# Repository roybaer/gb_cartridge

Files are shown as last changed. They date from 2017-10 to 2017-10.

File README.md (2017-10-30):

# GB Cartridge

This repository contains various PCB designs for Game Boy cartridges.

## Board characteristics

The individual designs have the following characteristics:

Board marking     | ROM    | RAM     | RAM backup                 | Technology | Memory Bank Controller
------------------|--------|---------|----------------------------|------------|--------------------------------
ROM+RAM(+BATT)    | 32 KiB | 8 KiB   | external battery/capacitor | SMD        | none
ROM+RAM+BATT      | 32 KiB | 8 KiB   | coin cell battery holder   | SMD        | none
ROM+RAM+BATT EVAL | 32 KiB | 8 KiB   | external battery           | THT        | none
ROM+MBC+RAM+BATT  | 1 MiB  | 128 KiB | coin cell battery holder   | SMD        | 74xx ICs loosely imitating MBC5

So far, only __ROM+RAM+BATT__ and __ROM+RAM+BATT EVAL__ have been manufactured and only the ROM related functionality has been tested.

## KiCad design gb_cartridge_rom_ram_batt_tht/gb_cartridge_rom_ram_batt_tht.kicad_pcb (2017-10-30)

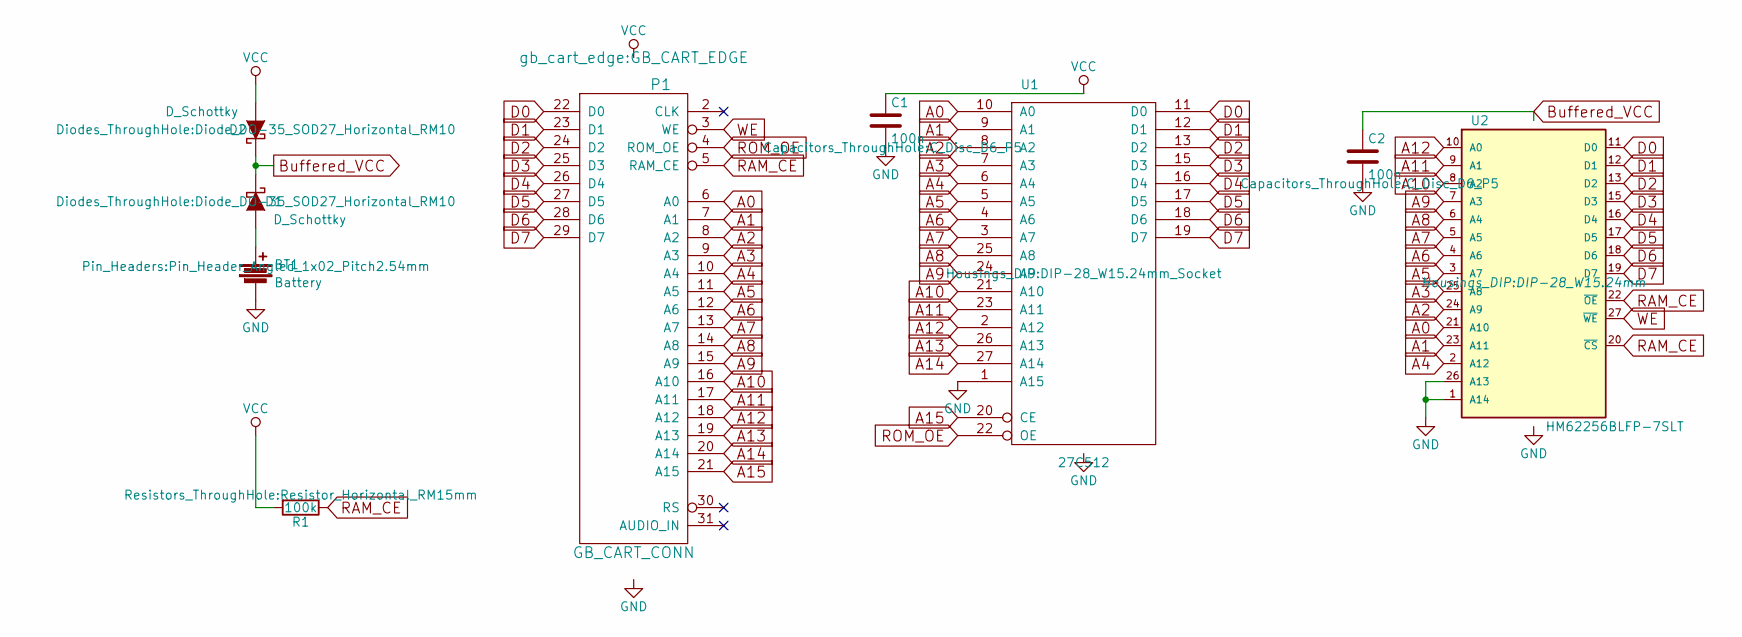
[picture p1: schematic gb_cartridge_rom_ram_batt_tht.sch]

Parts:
BT1: Battery; Pin_Header_Angled_1x02_Pitch2.54mm
C1, C2: 100n; C_Disc_D6_P5
D1, D2: D_Schottky; Diode_DO-35_SOD27_Horizontal_RM10
P1: GB_CART_CONN; GB_CART_EDGE
R1: 100k; Resistor_Horizontal_RM15mm
U1: 27C512; DIP-28_W15.24mm_Socket
U2: HM62256BLFP-7SLT; DIP-28_W15.24mm

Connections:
A0: P1.6 (A0), U1.10 (A0), U2.21 (A10)
A1: P1.7 (A1), U1.9 (A1), U2.23 (A11)
A2: P1.8 (A2), U1.8 (A2), U2.24 (A9)
A3: P1.9 (A3), U1.7 (A3), U2.25 (A8)
A4: P1.10 (A4), U1.6 (A4), U2.2 (A12)
A5: P1.11 (A5), U1.5 (A5), U2.3 (A7)
A6: P1.12 (A6), U1.4 (A6), U2.4 (A6)
A7: P1.13 (A7), U1.3 (A7), U2.5 (A5)
A8: P1.14 (A8), U1.25 (A8), U2.6 (A4)
A9: P1.15 (A9), U1.24 (A9), U2.7 (A3)
A10: P1.16 (A10), U1.21 (A10), U2.8 (A2)
A11: P1.17 (A11), U1.23 (A11), U2.9 (A1)
A12: P1.18 (A12), U1.2 (A12), U2.10 (A0)
A13: P1.19 (A13), U1.26 (A13)
A14: P1.20 (A14), U1.27 (A14)
A15: P1.21 (A15), U1.20 (CE)
D0: P1.22 (D0), U1.11 (D0), U2.11 (D0)
D1: P1.23 (D1), U1.12 (D1), U2.12 (D1)
D2: P1.24 (D2), U1.13 (D2), U2.13 (D2)
D3: P1.25 (D3), U1.15 (D3), U2.15 (D3)
D4: P1.26 (D4), U1.16 (D4), U2.16 (D4)
D5: P1.27 (D5), U1.17 (D5), U2.17 (D5)
D6: P1.28 (D6), U1.18 (D6), U2.18 (D6)
D7: P1.29 (D7), U1.19 (D7), U2.19 (D7)
GND: BT1.2, C1.2, C2.2, P1.32 (GND), U1.1 (A15), U1.14 (GND), U2.1 (A14), U2.14 (GND), U2.26 (A13)
unnamed: BT1.1, D1.2 (A)
RAM_CE: P1.5 (RAM_CE), R1.1, U2.20 (~CS), U2.22 (~OE)
ROM_OE: P1.4 (ROM_OE), U1.22 (OE)
WE: P1.3 (WE), U2.27 (~WE)

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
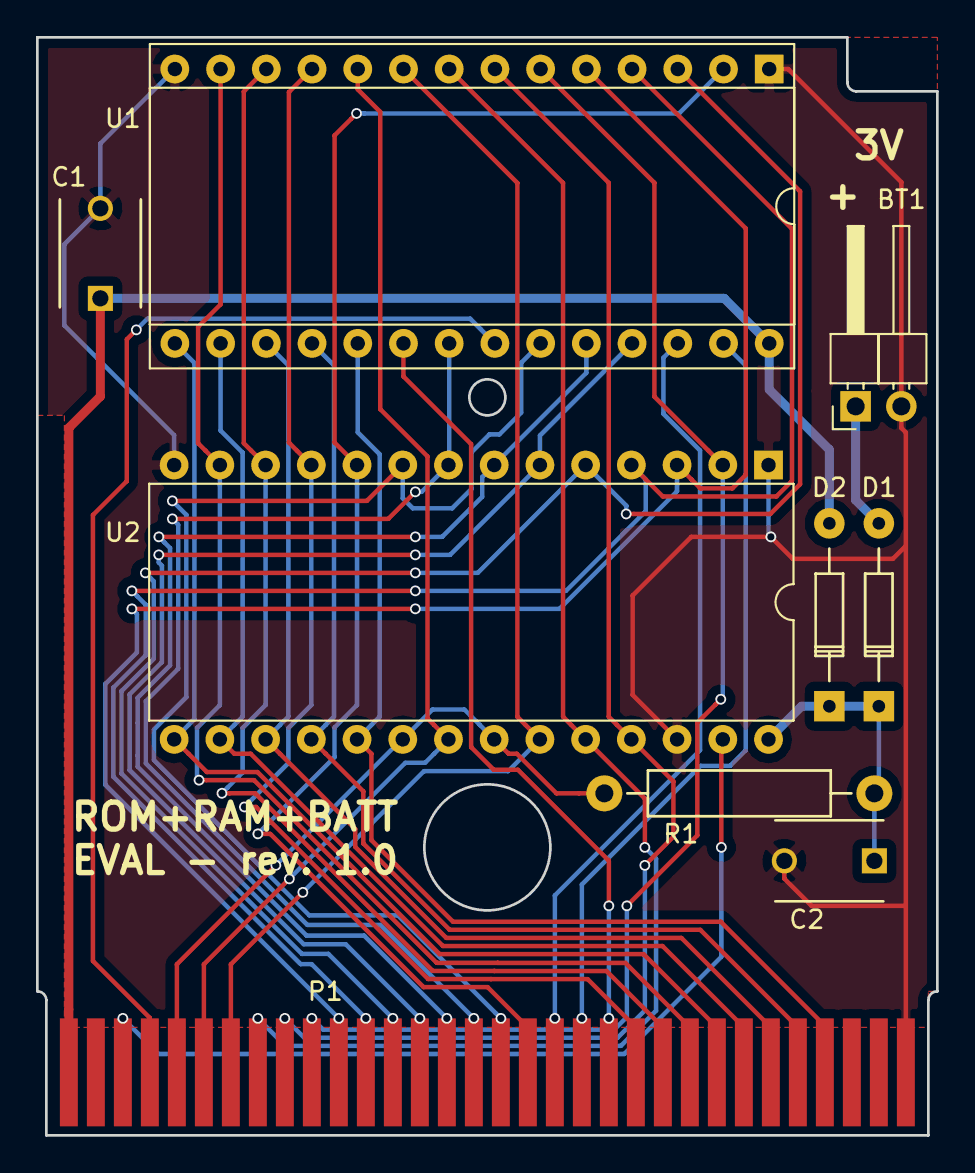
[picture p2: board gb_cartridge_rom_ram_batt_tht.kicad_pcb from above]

Board: 2 copper layers, 50.0 x 61.0 mm, 9 parts (0 on the bottom side), 30 nets.

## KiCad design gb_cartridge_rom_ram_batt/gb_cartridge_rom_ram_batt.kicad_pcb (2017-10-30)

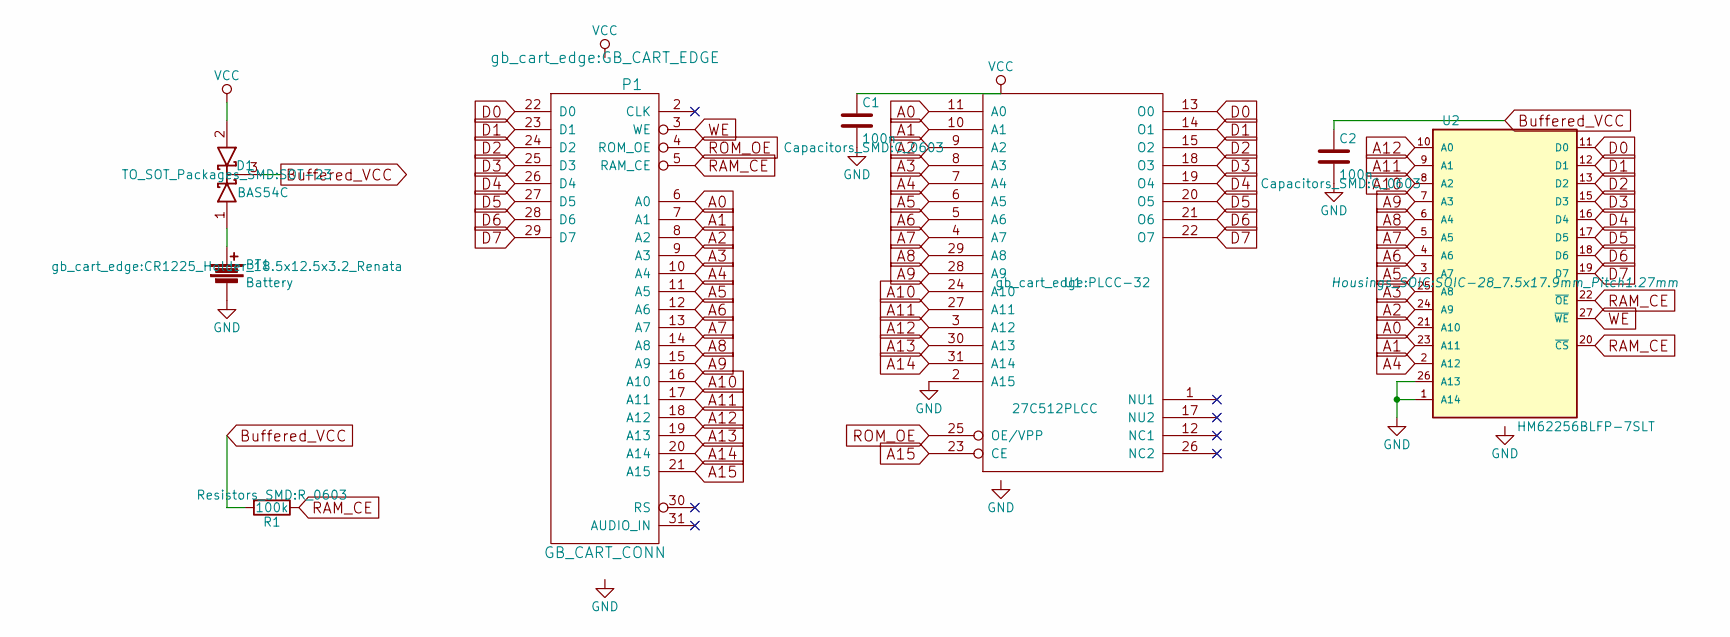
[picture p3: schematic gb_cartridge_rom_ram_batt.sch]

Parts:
BT1: Battery; CR1225_Holder_18.5x12.5x3.2_Renata
C1, C2: 100n; C_0603
D1: BAS54C; SOT-23
P1: GB_CART_CONN; GB_CART_EDGE
R1: 100k; R_0603
U1: 27C512PLCC; PLCC-32
U2: HM62256BLFP-7SLT; SOIC-28_7.5x17.9mm_Pitch1.27mm

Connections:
A0: P1.6 (A0), U1.11 (A0), U2.21 (A10)
A1: P1.7 (A1), U1.10 (A1), U2.23 (A11)
A2: P1.8 (A2), U1.9 (A2), U2.24 (A9)
A3: P1.9 (A3), U1.8 (A3), U2.25 (A8)
A4: P1.10 (A4), U1.7 (A4), U2.2 (A12)
A5: P1.11 (A5), U1.6 (A5), U2.3 (A7)
A6: P1.12 (A6), U1.5 (A6), U2.4 (A6)
A7: P1.13 (A7), U1.4 (A7), U2.5 (A5)
A8: P1.14 (A8), U1.29 (A8), U2.6 (A4)
A9: P1.15 (A9), U1.28 (A9), U2.7 (A3)
A10: P1.16 (A10), U1.24 (A10), U2.8 (A2)
A11: P1.17 (A11), U1.27 (A11), U2.9 (A1)
A12: P1.18 (A12), U1.3 (A12), U2.10 (A0)
A13: P1.19 (A13), U1.30 (A13)
A14: P1.20 (A14), U1.31 (A14)
A15: P1.21 (A15), U1.23 (CE)
D0: P1.22 (D0), U1.13 (O0), U2.11 (D0)
D1: P1.23 (D1), U1.14 (O1), U2.12 (D1)
D2: P1.24 (D2), U1.15 (O2), U2.13 (D2)
D3: P1.25 (D3), U1.18 (O3), U2.15 (D3)
D4: P1.26 (D4), U1.19 (O4), U2.16 (D4)
D5: P1.27 (D5), U1.20 (O5), U2.17 (D5)
D6: P1.28 (D6), U1.21 (O6), U2.18 (D6)
D7: P1.29 (D7), U1.22 (O7), U2.19 (D7)
GND: BT1.2, C1.2, C2.2, P1.32 (GND), U1.2 (A15), U1.16 (GND), U2.1 (A14), U2.14 (GND), U2.26 (A13)
unnamed: BT1.1, D1.1 (A)
RAM_CE: P1.5 (RAM_CE), R1.1, U2.20 (~CS), U2.22 (~OE)
ROM_OE: P1.4 (ROM_OE), U1.25 (OE/VPP)
WE: P1.3 (WE), U2.27 (~WE)

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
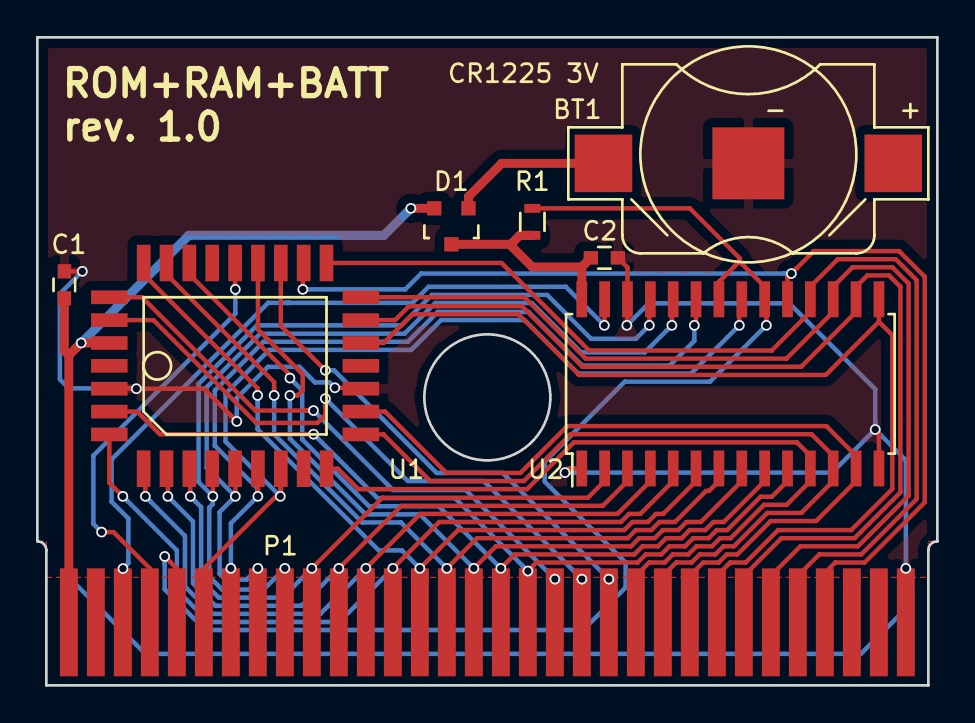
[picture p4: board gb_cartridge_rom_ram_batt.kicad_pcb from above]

Board: 2 copper layers, 50.0 x 36.0 mm, 8 parts (0 on the bottom side), 30 nets.

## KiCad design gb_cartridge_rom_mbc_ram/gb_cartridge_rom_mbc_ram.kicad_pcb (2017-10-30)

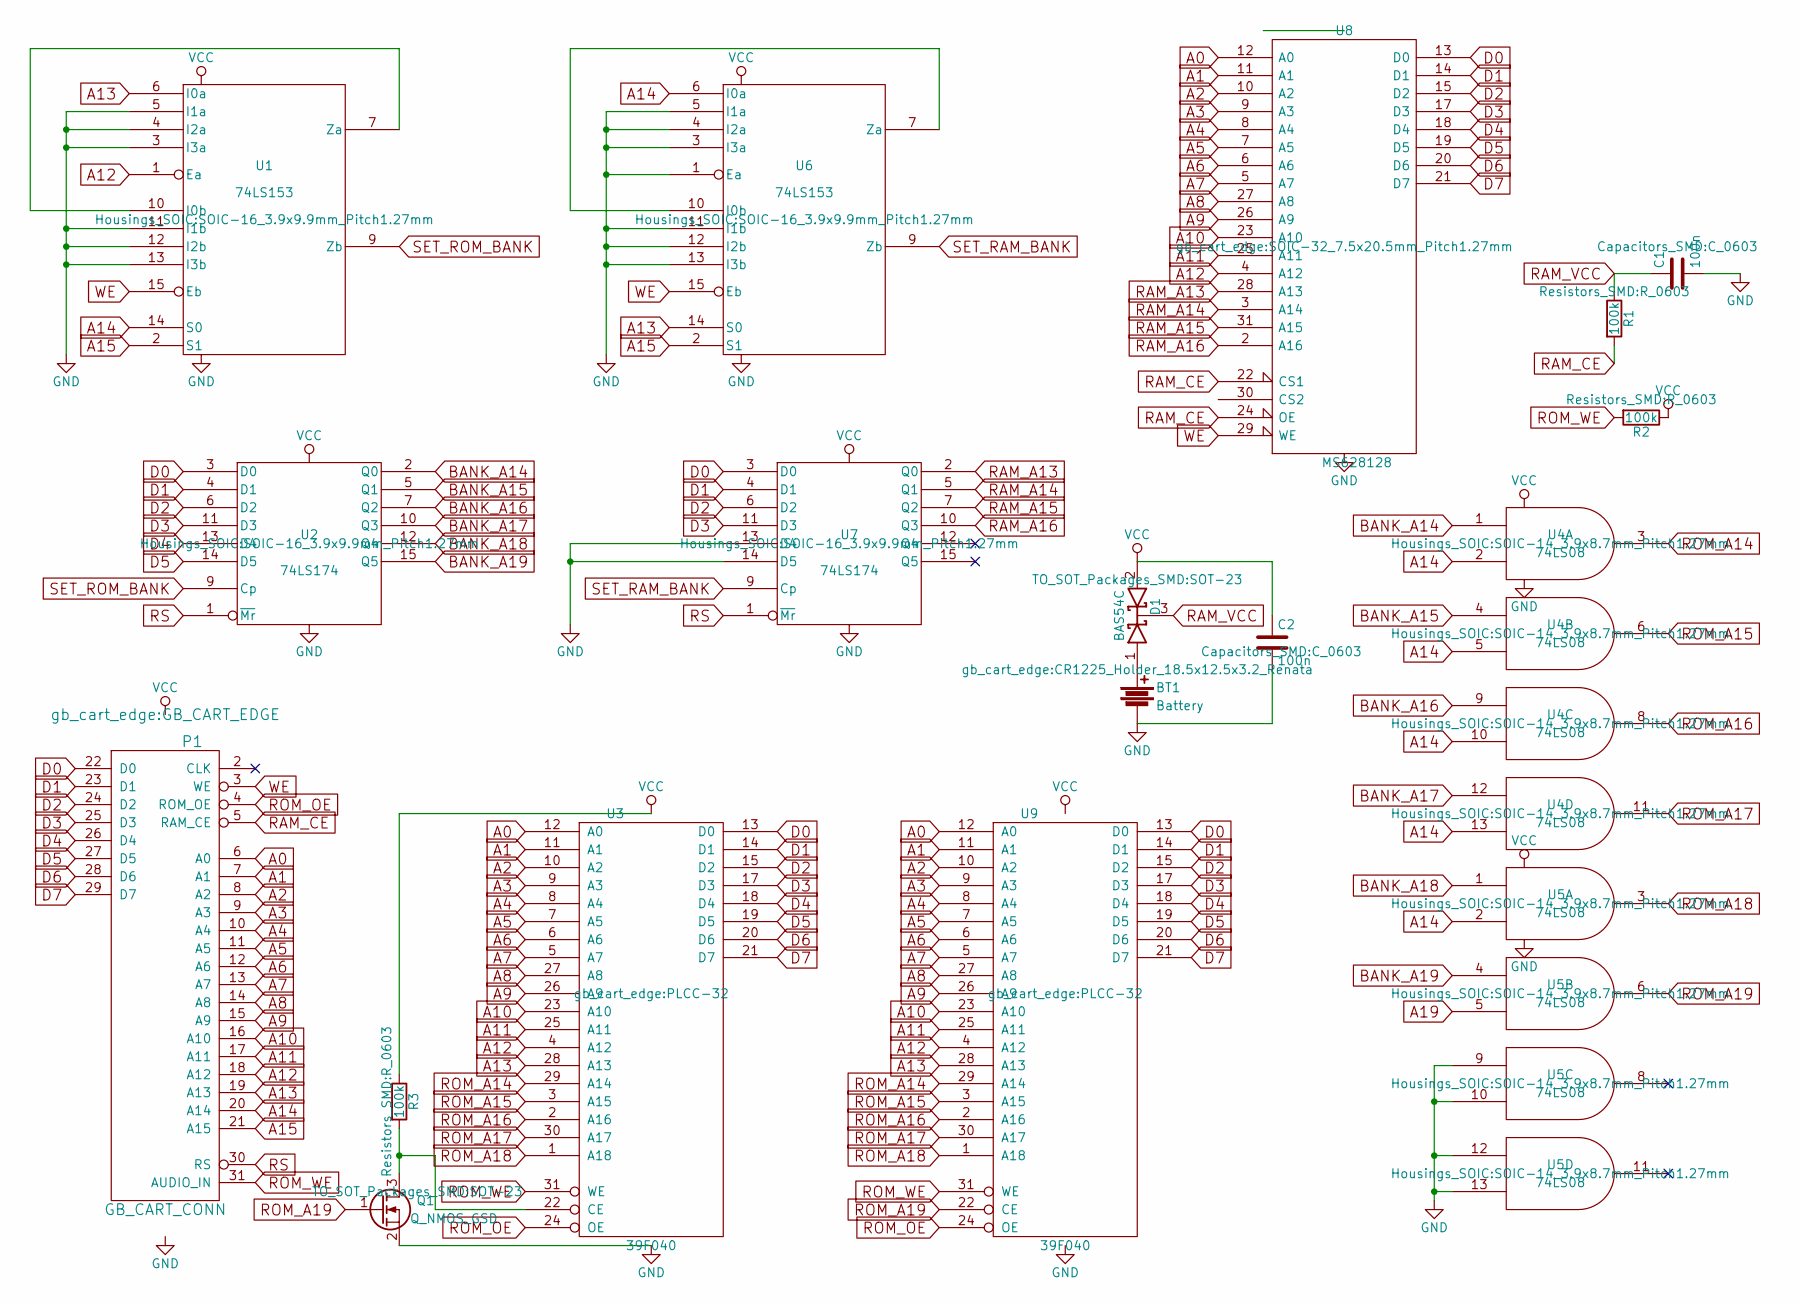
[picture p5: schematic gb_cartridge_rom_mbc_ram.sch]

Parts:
BT1: Battery; CR1225_Holder_18.5x12.5x3.2_Renata
C1, C2: 100n; C_0603
D1: BAS54C; SOT-23
P1: GB_CART_CONN; GB_CART_EDGE
Q1: Q_NMOS_GSD; SOT-23
R1, R2, R3: 100k; R_0603
U1, U6: 74LS153; SOIC-16_3.9x9.9mm_Pitch1.27mm
U2, U7: 74LS174; SOIC-16_3.9x9.9mm_Pitch1.27mm
U3, U9: 39F040; PLCC-32
U4, U5: 74LS08; SOIC-14_3.9x8.7mm_Pitch1.27mm
U8: MS628128; SOIC-32_7.5x20.5mm_Pitch1.27mm

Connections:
A0: P1.6 (A0), U3.12 (A0), U8.12 (A0), U9.12 (A0)
A1: P1.7 (A1), U3.11 (A1), U8.11 (A1), U9.11 (A1)
A2: P1.8 (A2), U3.10 (A2), U8.10 (A2), U9.10 (A2)
A3: P1.9 (A3), U3.9 (A3), U8.9 (A3), U9.9 (A3)
A4: P1.10 (A4), U3.8 (A4), U8.8 (A4), U9.8 (A4)
A5: P1.11 (A5), U3.7 (A5), U8.7 (A5), U9.7 (A5)
A6: P1.12 (A6), U3.6 (A6), U8.6 (A6), U9.6 (A6)
A7: P1.13 (A7), U3.5 (A7), U8.5 (A7), U9.5 (A7)
A8: P1.14 (A8), U3.27 (A8), U8.27 (A8), U9.27 (A8)
A9: P1.15 (A9), U3.26 (A9), U8.26 (A9), U9.26 (A9)
A10: P1.16 (A10), U3.23 (A10), U8.23 (A10), U9.23 (A10)
A11: P1.17 (A11), U3.25 (A11), U8.25 (A11), U9.25 (A11)
A12: P1.18 (A12), U1.1 (Ea), U3.4 (A12), U8.4 (A12), U9.4 (A12)
A13: P1.19 (A13), U1.6 (I0a), U3.28 (A13), U6.14 (S0), U9.28 (A13)
A14: P1.20 (A14), U1.14 (S0), U4.2, U4.5, U4.10, U4.13, U5.2, U6.6 (I0a)
A15: P1.21 (A15), U1.2 (S1), U6.2 (S1)
A19: U5.5
BANK_A14: U2.2 (Q0), U4.1
BANK_A15: U2.5 (Q1), U4.4
BANK_A16: U2.7 (Q2), U4.9
BANK_A17: U2.10 (Q3), U4.12
BANK_A18: U2.12 (Q4), U5.1
BANK_A19: U2.15 (Q5), U5.4
D0: P1.22 (D0), U2.3 (D0), U3.13 (D0), U7.3 (D0), U8.13 (D0), U9.13 (D0)
D1: P1.23 (D1), U2.4 (D1), U3.14 (D1), U7.4 (D1), U8.14 (D1), U9.14 (D1)
D2: P1.24 (D2), U2.6 (D2), U3.15 (D2), U7.6 (D2), U8.15 (D2), U9.15 (D2)
D3: P1.25 (D3), U2.11 (D3), U3.17 (D3), U7.11 (D3), U8.17 (D3), U9.17 (D3)
D4: P1.26 (D4), U2.13 (D4), U3.18 (D4), U8.18 (D4), U9.18 (D4)
D5: P1.27 (D5), U2.14 (D5), U3.19 (D5), U8.19 (D5), U9.19 (D5)
D6: P1.28 (D6), U3.20 (D6), U8.20 (D6), U9.20 (D6)
D7: P1.29 (D7), U3.21 (D7), U8.21 (D7), U9.21 (D7)
GND: BT1.2, C1.2, C2.2, P1.32 (GND), Q1.2 (S), U1.3 (I3a), U1.4 (I2a), U1.5 (I1a), U1.8 (GND), U1.11 (I1b), U1.12 (I2b), U1.13 (I3b), U2.8 (GND), U3.16 (GND), U4.7 (GND), U5.7 (GND), U5.9, U5.10, U5.12, U5.13, U6.1 (Ea), U6.3 (I3a), U6.4 (I2a), U6.5 (I1a), U6.8 (GND), U6.11 (I1b), U6.12 (I2b), U6.13 (I3b), U7.8 (GND), U7.13 (D4), U7.14 (D5), U8.16 (GND), U9.16 (GND)
unnamed: BT1.1, D1.1 (A)
unnamed: Q1.3 (D), R3.2, U3.22 (CE)
unnamed: U1.7 (Za), U1.10 (I0b)
unnamed: U6.7 (Za), U6.10 (I0b)
RAM_A13: U7.2 (Q0), U8.28 (A13)
RAM_A14: U7.5 (Q1), U8.3 (A14)
RAM_A15: U7.7 (Q2), U8.31 (A15)
RAM_A16: U7.10 (Q3), U8.2 (A16)
RAM_CE: P1.5 (RAM_CE), R1.2, U8.22 (CS1), U8.24 (OE)
RAM_VCC: C1.1, D1.3 (K), R1.1
ROM_A14: U3.29 (A14), U4.3, U9.29 (A14)
ROM_A15: U3.3 (A15), U4.6, U9.3 (A15)
ROM_A16: U3.2 (A16), U4.8, U9.2 (A16)
ROM_A17: U3.30 (A17), U4.11, U9.30 (A17)
ROM_A18: U3.1 (A18), U5.3, U9.1 (A18)
ROM_A19: Q1.1 (G), U5.6, U9.22 (CE)
ROM_OE: P1.4 (ROM_OE), U3.24 (OE), U9.24 (OE)
ROM_WE: P1.31 (AUDIO_IN), R2.2, U3.31 (WE), U9.31 (WE)
RS: P1.30 (RS), U2.1 (~Mr), U7.1 (~Mr)
SET_RAM_BANK: U6.9 (Zb), U7.9 (Cp)
SET_ROM_BANK: U1.9 (Zb), U2.9 (Cp)
VCC: C2.1, D1.2 (A), P1.1 (VCC), R2.1, R3.1, U1.16 (VCC), U2.16 (VCC), U3.32 (VCC), U4.14 (VCC), U5.14 (VCC), U6.16 (VCC), U7.16 (VCC), U8.32 (VCC), U9.32 (VCC)
WE: P1.3 (WE), U1.15 (Eb), U6.15 (Eb), U8.29 (WE)

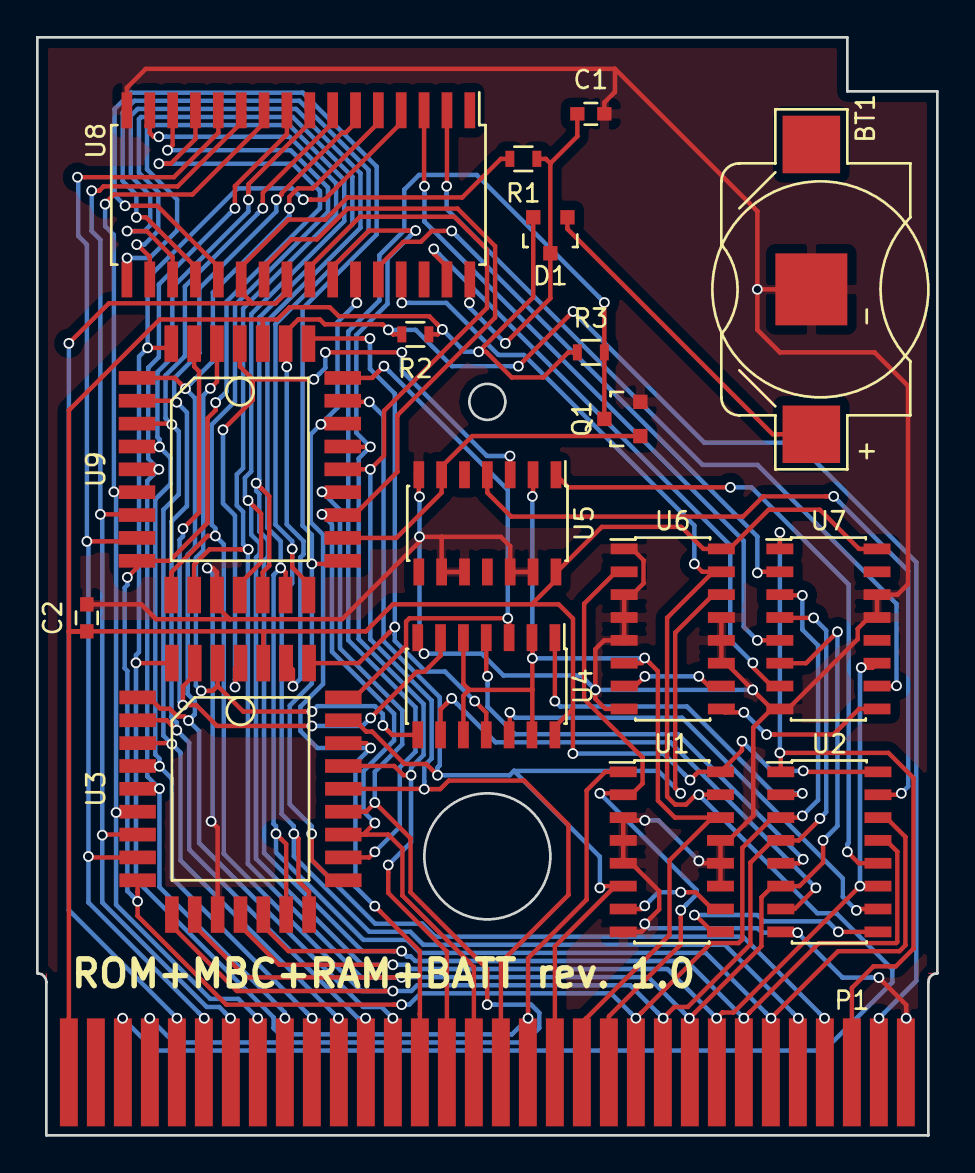
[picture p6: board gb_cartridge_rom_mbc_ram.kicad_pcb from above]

Board: 2 copper layers, 50.0 x 61.0 mm, 18 parts (0 on the bottom side), 54 nets.

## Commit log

2017-10-30 cartridge with ROM, RAM and wire pads for a backup battery/capacitor
    [gb_cartridge_rom_ram.kicad_pcb, gb_cartridge_rom_ram.sch]
2017-10-30 cartridge with ROM, RAM, bank switching logic and backup battery
    [gb_cartridge_rom_mbc_ram.kicad_pcb, gb_cartridge_rom_mbc_ram.sch]
2017-10-30 cartridge with ROM, RAM and backup battery (SMD)
    [gb_cartridge_rom_ram_batt.kicad_pcb, gb_cartridge_rom_ram_batt.sch]
2017-10-30 cartridge with ROM, RAM and backup battery connector (THT)
    [gb_cartridge_rom_ram_batt_tht.kicad_pcb, gb_cartridge_rom_ram_batt_tht.sch]
